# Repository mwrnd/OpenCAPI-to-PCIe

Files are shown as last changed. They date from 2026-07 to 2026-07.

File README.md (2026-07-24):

# PCIe to OpenCAPI-Compatible SlimSAS 8x

The [Open Coherant Accelerator Processor Interface (OpenCAPI)](https://opencapi.org/wp-content/uploads/2022/07/OpenCAPI-Overview.pdf) [was a standard](https://opencapi.org/2022/08/09/cxl-consortium-and-opencapi-consortium-sign-letter-of-intent-to-transfer-opencapi-specifications-to-cxl/) that had FPGA-based [Advanced Accelerated Cable (AAC)](https://files.openpower.foundation/s/xSQPe6ypoakKQdq/download/25Gbps-spec-20171108.pdf) [Add-In cards](https://opencapi.org/wp-content/uploads/2018/12/OpenCAPI-Tech-SC18-Exhibitor-Forum.pdf) such as [ADM-PCIE-9H3](https://www.alpha-data.com/product/adm-pcie-9h3/), [ADM-PCIE-9H7](https://www.alpha-data.com/alpha-data-release-adm-pcie-9h7-data-center-board-with-xilinx-virtex-ultrascale-hbm-fpga/), [ADM-PCIE-9V3](https://www.alpha-data.com/product/adm-pcie-9v3/), [ADM-PCIE-9V5](https://www.alpha-data.com/product/adm-pcie-9v5/), [BittWare XUP-VV4](https://www.bittware.com/fpga/xup-vv4/), [BittWare XUP-VVH](https://www.bittware.com/fpga/xup-vvh/), and [Nvidia Innova-2 Flex](https://www.nvidia.com/en-us/networking/ethernet/innova-2-flex/).

The OpenCAPI SlimSAS interface is based on [PCI-Express](https://en.wikipedia.org/wiki/PCI_Express). This project is an adapter capable of connecting such FPGA boards to host systmes with PCIe.

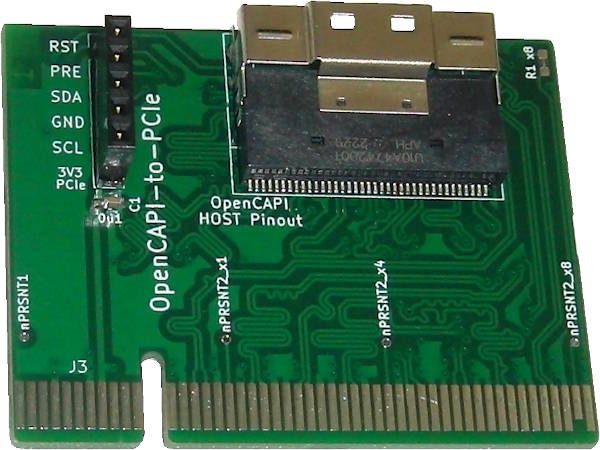
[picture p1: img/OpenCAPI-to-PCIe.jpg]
OpenCAPI-to-PCIe Adapter


This design uses the OpenCAPI pinout from the [ADM-PCIE-9V5 User Manual (Pg15-19of38)](https://www.alpha-data.com/xml/user_manuals/adm-pcie-9v5%20user%20manual_v1_4.pdf):

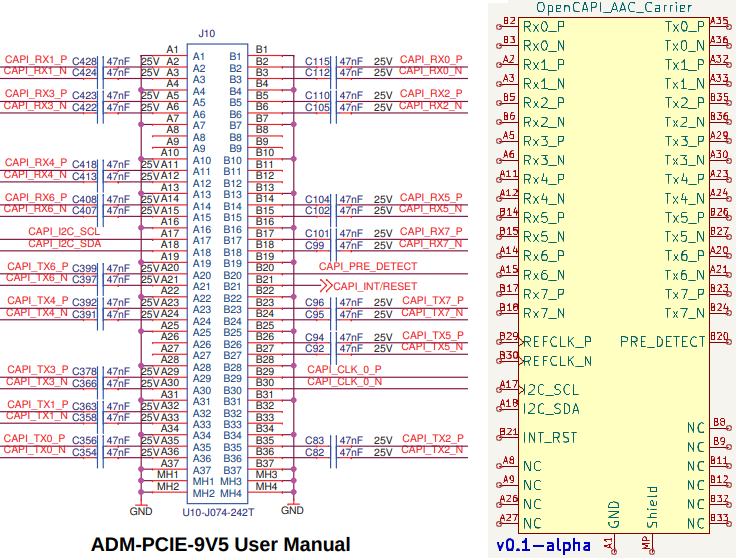
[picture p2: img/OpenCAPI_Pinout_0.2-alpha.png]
OpenCAPI Pinout from


The only OpenCAPI board I have to test against is the **Innova-2 MNV303212A-ADLT Rev:A2** and I designed the [OpenCAPI-to-PCIe_for_MNV303212A_RevA2](https://github.com/mwrnd/OpenCAPI-to-PCIe_for_MNV303212A_RevA2) project as an optimized variant of this design for that board.

## Issues when used with the Innova-2 MNV303212A RevA2

The [current v0.2 release](https://github.com/mwrnd/OpenCAPI-to-PCIe/releases/tag/v0.2) of this project worked with the [First Release of the `innova2_xdma_opencapi`](https://github.com/mwrnd/innova2_xdma_opencapi/tree/348716249bafc39514cb1a422a8e2fb5f301f859) project:

```
git clone --revision=348716249bafc39514cb1a422a8e2fb5f301f859 https://github.com/mwrnd/innova2_xdma_opencapi.git
wget https://github.com/mwrnd/innova2_xdma_opencapi/releases/download/v0.1/innova2_xdma_opencapi_bitstream.zip
```

But, it required a [non-standard GTY Channel to PCIe Lane mapping](https://github.com/mwrnd/innova2_xdma_opencapi/blob/348716249bafc39514cb1a422a8e2fb5f301f859/compile.tcl#L14) that Vivado complains about:

Vivado Critical Warning about Lane Ordering

The [OpenCAPI-to-PCIe_for_MNV303212A_RevA2](https://github.com/mwrnd/OpenCAPI-to-PCIe_for_MNV303212A_RevA2) project is a version of this adapter optimized for the Innova-2 **MNV303212A Rev:A2**.

# PCB Layout

4-Layer PCB. Inner 2 layers are GND planes. Differential pairs are matched to a length of 65mm +/- 1mm both inter-pair and intra-pair (N-to-P).

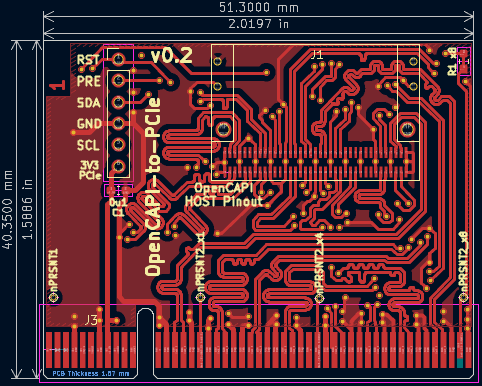
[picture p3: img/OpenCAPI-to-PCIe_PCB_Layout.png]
OpenCAPI to PCIe x8 PCB Layout


# Schematic

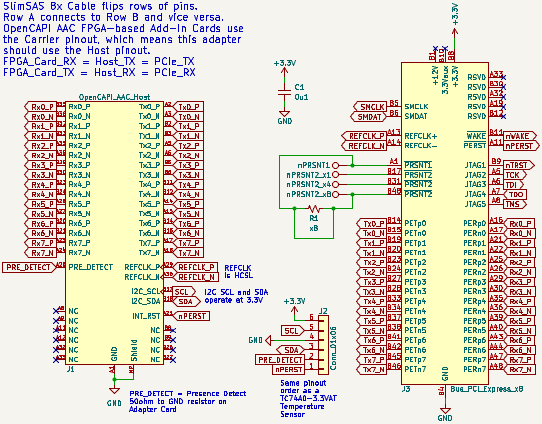
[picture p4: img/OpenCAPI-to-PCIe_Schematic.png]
OpenCAPI to PCIe x8 Schematic


## Design Notes

Refer to the [ADM-PCIE-9V5 User Manual (Pg15-19of38)](https://www.alpha-data.com/xml/user_manuals/adm-pcie-9v5%20user%20manual_v1_4.pdf). Useful [High Speed Design presentation](https://www.youtube.com/watch?v=QG0Apol-oj0&t=2832s).

Only a single component is needed for the adapter, a [U10A474200T](https://www.digikey.com/en/products/detail/amphenol-cs-commercial-products/U10A474200T/14632855)/[U10A474240T](https://www.digikey.com/en/products/detail/amphenol-cs-commercial-products/U10A474240T/17066204) SlimSAS 8x Right-Angle SMD Connector.

A SlimSAS 8x Cable such as the [3M 8ES8-1DF21](https://www.trustedparts.com/en/search/8ES8-1DF21)([Datasheet](https://multimedia.3m.com/mws/media/1398233O/3m-slimline-twin-ax-assembly-sff-8654-x8-30awg-78-5100-2665-8.pdf)) is required to use the adapter with an OpenCAPI FPGA Board.

Resistor **R1** is shorted to connect `nPRSNT1` to `nPRSNT2_x8`. The trace can be scratched off and `nPRSNT1` can be connected to `nPRSNT2_x1` or `nPRSNT2_x4` to limit the PCIe lane width.

Additional useful signals from the OpenCAPI connector are routed to a 6x1 0.1" Header ([DigiKey](https://www.digikey.com/en/products/detail/sullins-connector-solutions/PPTC061LFBN-RC/810145)). The pinout matches a [TC74 I2C Temperature Sensor](https://www.microchip.com/en-us/product/tc74) ([DigiKey](https://www.digikey.com/en/products/detail/microchip-technology/TC74A0-3-3VAT/442720)) for testing I2C. I2C pull-ups are on the AAC Add-in card. Note 3.3V is from the PCIe connector. **PRE** is a Presence Detect pin which is connected to GND via a 50-Ohm resistor on the OpenCAPI AAC Add-In card. **RST** is connected to PCIe/OpenCAPI RESET.

### PCB Stackup

I am using values from [JLCPCB](https://jlcpcb.com/capabilities/pcb-capabilities).

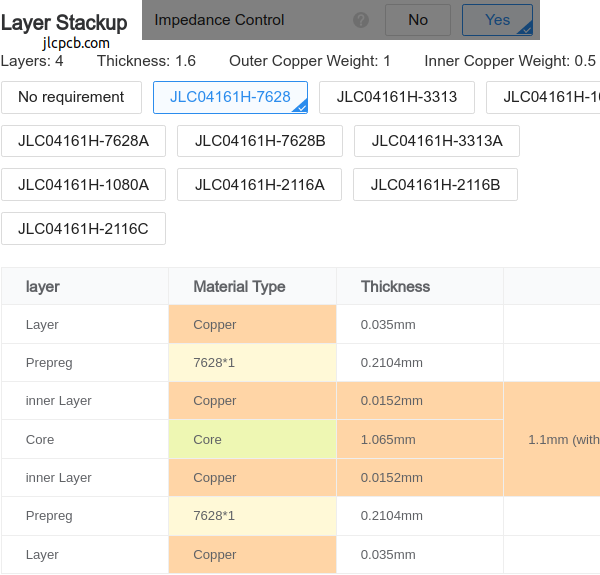
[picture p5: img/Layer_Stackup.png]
4-Layer Stackup


### Trace Impedance Control

OpenCAPI uses 85ohm impedance cables. I played with the values until I got the loosest differential pair coupling that is manufacturable with larger tolerances.

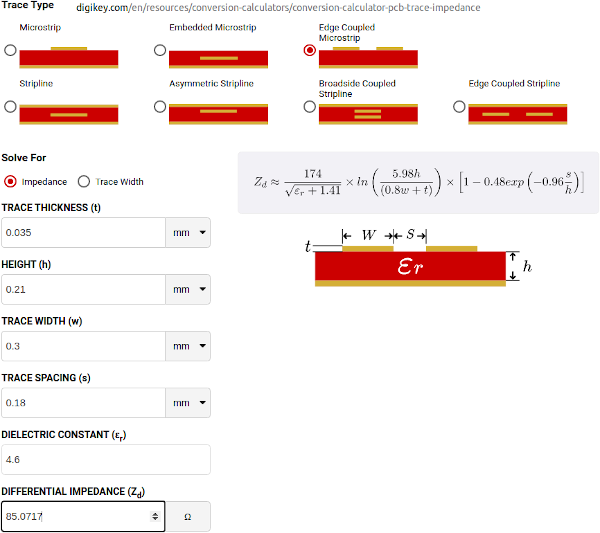
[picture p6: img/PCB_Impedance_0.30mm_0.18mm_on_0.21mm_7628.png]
85ohm Differential Impedance in DigiKey Calculator


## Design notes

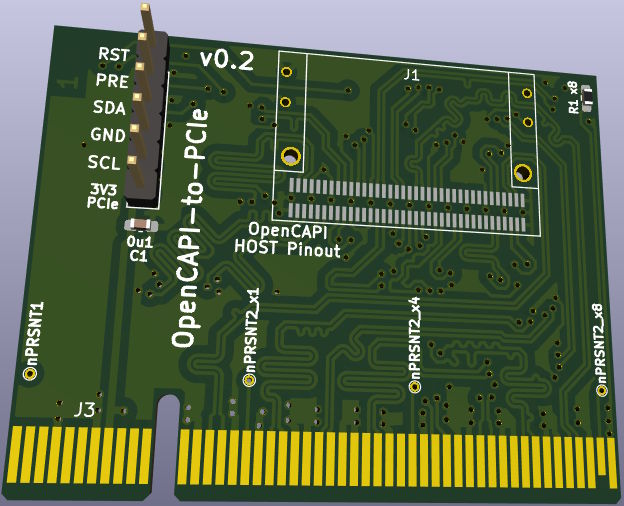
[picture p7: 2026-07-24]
img/OpenCAPI-to-PCIe_3D.jpg

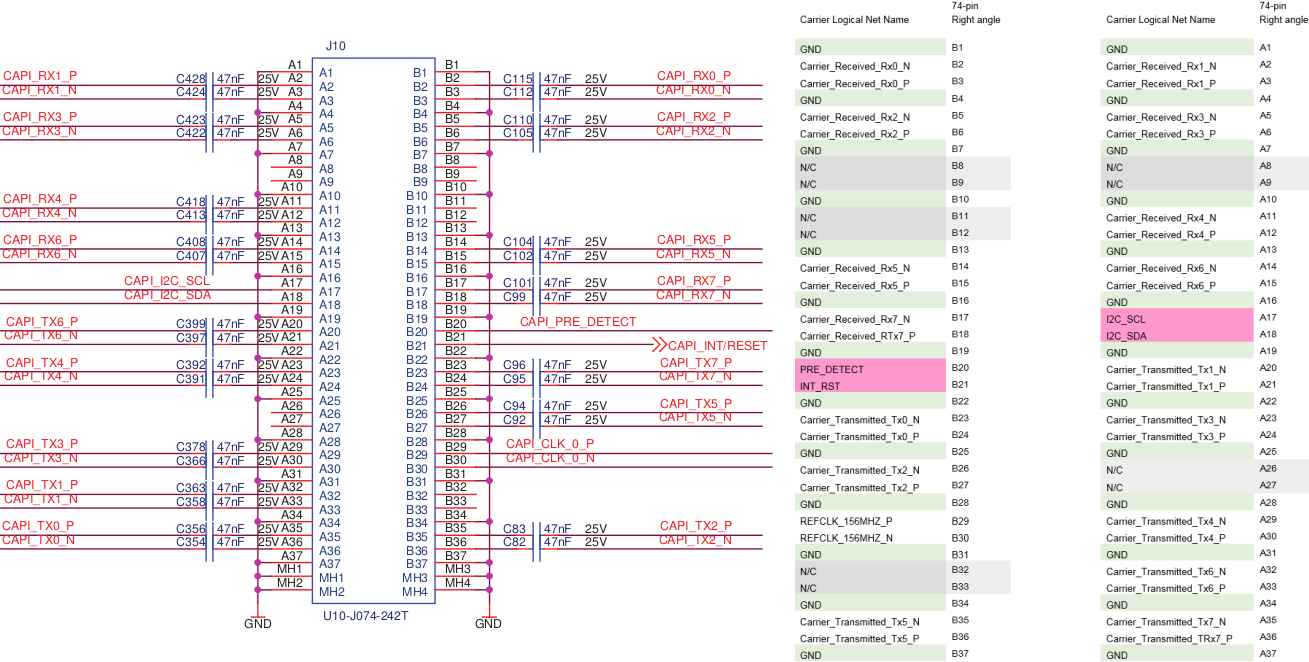
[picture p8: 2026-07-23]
img/OpenCAPI_Error.png

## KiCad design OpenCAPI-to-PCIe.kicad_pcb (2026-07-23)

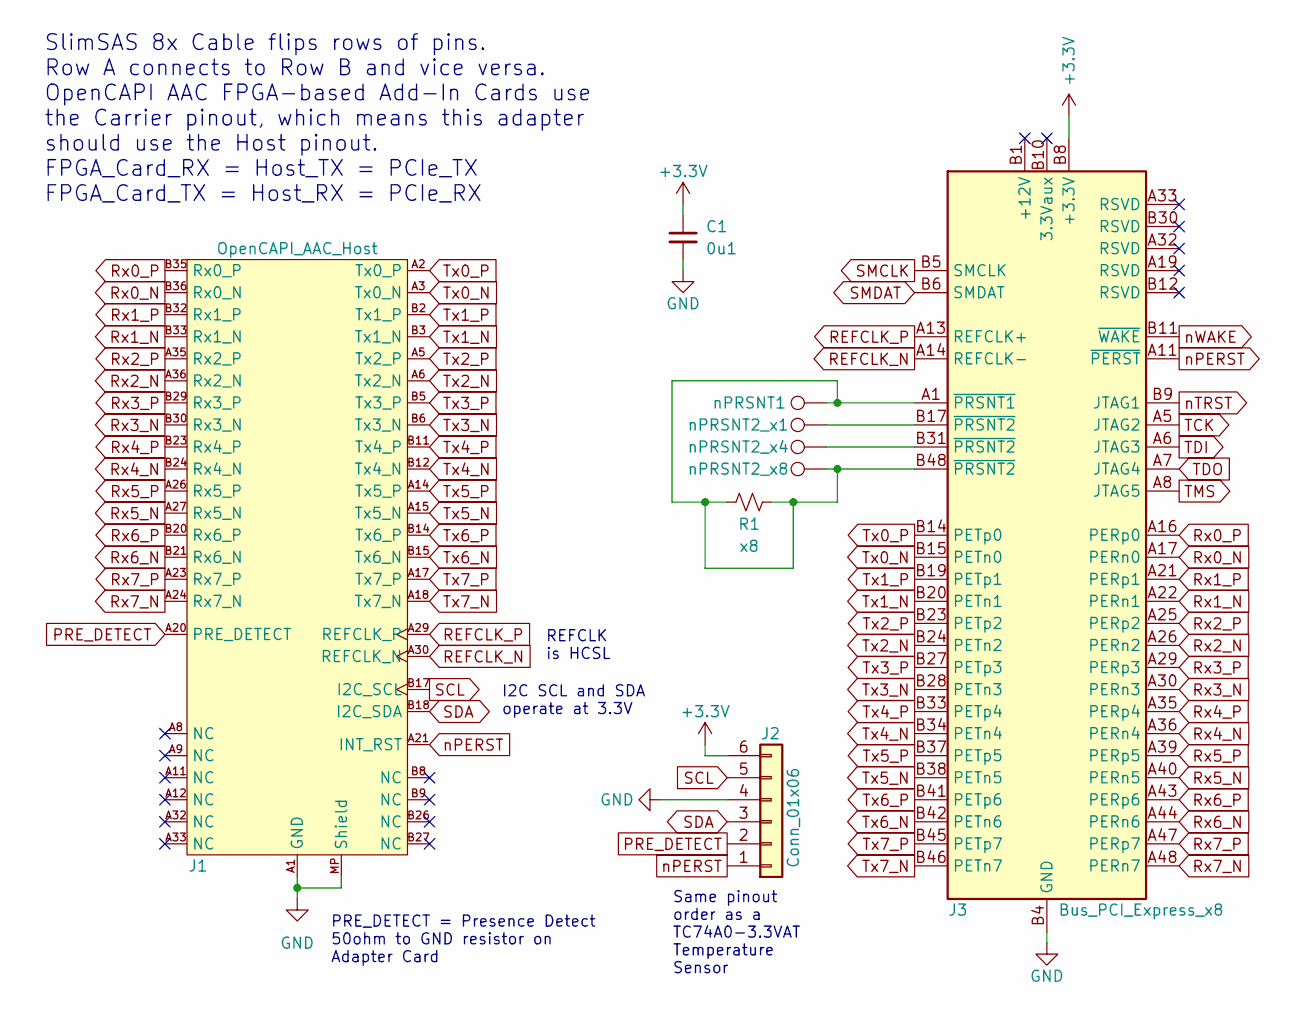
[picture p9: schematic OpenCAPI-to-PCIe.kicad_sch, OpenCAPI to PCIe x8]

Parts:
C1: 0u1; C_0603_1608Metric_Pad1.08x0.95mm_HandSolder
J1: OpenCAPI_AAC_Host; SlimSAS_8x_RA_U10-A474
J2: Conn_01x06; PinHeader_1x06_P2.54mm_Vertical
J3: Bus_PCI_Express_x8; BUS_PCIexpress_x8
R1: x8; R_0603_1608Metric_Pad0.98x0.95mm_HandSolder
TP1: nPRSNT1; TestPoint_THTPad_D1.0mm_Drill0.5mm
TP2: nPRSNT2_x1; TestPoint_THTPad_D1.0mm_Drill0.5mm
TP3: nPRSNT2_x4; TestPoint_THTPad_D1.0mm_Drill0.5mm
TP5: nPRSNT2_x8; TestPoint_THTPad_D1.0mm_Drill0.5mm

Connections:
+3.3V: C1.1, J2.6, J3.A9 (+3.3V), J3.A10 (+3.3V), J3.B8 (+3.3V)
GND: C1.2, J1.A1 (GND), J1.A4 (GND), J1.A7 (GND), J1.A10 (GND), J1.A13 (GND), J1.A16 (GND), J1.A19 (GND), J1.A22 (GND), J1.A25 (GND), J1.A28 (GND), J1.A31 (GND), J1.A34 (GND), J1.A37 (GND), J1.B1 (GND), J1.B4 (GND), J1.B7 (GND), J1.B10 (GND), J1.B13 (GND), J1.B16 (GND), J1.B19 (GND), J1.B22 (GND), J1.B25 (GND), J1.B28 (GND), J1.B31 (GND), J1.B34 (GND), J1.B37 (GND), J1.MP (Shield), J2.4, J3.A4 (GND), J3.A12 (GND), J3.A15 (GND), J3.A18 (GND), J3.A20 (GND), J3.A23 (GND), J3.A24 (GND), J3.A27 (GND), J3.A28 (GND), J3.A31 (GND), J3.A34 (GND), J3.A37 (GND), J3.A38 (GND), J3.A41 (GND), J3.A42 (GND), J3.A45 (GND), J3.A46 (GND), J3.A49 (GND), J3.B4 (GND), J3.B7 (GND), J3.B13 (GND), J3.B16 (GND), J3.B18 (GND), J3.B21 (GND), J3.B22 (GND), J3.B25 (GND), J3.B26 (GND), J3.B29 (GND), J3.B32 (GND), J3.B35 (GND), J3.B36 (GND), J3.B39 (GND), J3.B40 (GND), J3.B43 (GND), J3.B44 (GND), J3.B47 (GND), J3.B49 (GND)
unnamed: J3.A1 (~PRSNT1), J3.B48 (~PRSNT2), R1.1, R1.2, TP1.1, TP5.1
unnamed: J3.B17 (~PRSNT2), TP2.1
unnamed: J3.B31 (~PRSNT2), TP3.1
PRE_DETECT: J1.A20 (PRE_DETECT), J2.2
REFCLK_N: J1.A30 (REFCLK_N), J3.A14 (REFCLK-)
REFCLK_P: J1.A29 (REFCLK_P), J3.A13 (REFCLK+)
Rx0_N: J1.B36 (Rx0_N), J3.A17 (PERn0)
Rx0_P: J1.B35 (Rx0_P), J3.A16 (PERp0)
Rx1_N: J1.B33 (Rx1_N), J3.A22 (PERn1)
Rx1_P: J1.B32 (Rx1_P), J3.A21 (PERp1)
Rx2_N: J1.A36 (Rx2_N), J3.A26 (PERn2)
Rx2_P: J1.A35 (Rx2_P), J3.A25 (PERp2)
Rx3_N: J1.B30 (Rx3_N), J3.A30 (PERn3)
Rx3_P: J1.B29 (Rx3_P), J3.A29 (PERp3)
Rx4_N: J1.B24 (Rx4_N), J3.A36 (PERn4)
Rx4_P: J1.B23 (Rx4_P), J3.A35 (PERp4)
Rx5_N: J1.A27 (Rx5_N), J3.A40 (PERn5)
Rx5_P: J1.A26 (Rx5_P), J3.A39 (PERp5)
Rx6_N: J1.B21 (Rx6_N), J3.A44 (PERn6)
Rx6_P: J1.B20 (Rx6_P), J3.A43 (PERp6)
Rx7_N: J1.A24 (Rx7_N), J3.A48 (PERn7)
Rx7_P: J1.A23 (Rx7_P), J3.A47 (PERp7)
SCL: J1.B17 (I2C_SCL), J2.5
SDA: J1.B18 (I2C_SDA), J2.3
SMCLK: J3.B5 (SMCLK)
SMDAT: J3.B6 (SMDAT)
TCK: J3.A5 (JTAG2)
TDI: J3.A6 (JTAG3)
TDO: J3.A7 (JTAG4)
TMS: J3.A8 (JTAG5)
Tx0_N: J1.A3 (Tx0_N), J3.B15 (PETn0)
Tx0_P: J1.A2 (Tx0_P), J3.B14 (PETp0)
Tx1_N: J1.B3 (Tx1_N), J3.B20 (PETn1)
Tx1_P: J1.B2 (Tx1_P), J3.B19 (PETp1)
Tx2_N: J1.A6 (Tx2_N), J3.B24 (PETn2)
Tx2_P: J1.A5 (Tx2_P), J3.B23 (PETp2)
Tx3_N: J1.B6 (Tx3_N), J3.B28 (PETn3)
Tx3_P: J1.B5 (Tx3_P), J3.B27 (PETp3)
Tx4_N: J1.B12 (Tx4_N), J3.B34 (PETn4)
Tx4_P: J1.B11 (Tx4_P), J3.B33 (PETp4)
Tx5_N: J1.A15 (Tx5_N), J3.B38 (PETn5)
Tx5_P: J1.A14 (Tx5_P), J3.B37 (PETp5)
Tx6_N: J1.B15 (Tx6_N), J3.B42 (PETn6)
Tx6_P: J1.B14 (Tx6_P), J3.B41 (PETp6)
Tx7_N: J1.A18 (Tx7_N), J3.B46 (PETn7)
Tx7_P: J1.A17 (Tx7_P), J3.B45 (PETp7)
nPERST: J1.A21 (INT_RST), J2.1, J3.A11 (~PERST)
nTRST: J3.B9 (JTAG1)
nWAKE: J3.B11 (~WAKE)

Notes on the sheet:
I2C SCL and SDA operate at 3.3V
Same pinout order as a TC74A0-3.3VAT Temperature Sensor
REFCLK is HCSL
SlimSAS 8x Cable flips rows of pins. Row A connects to Row B and vice versa. OpenCAPI AAC FPGA-based Add-In Cards use the Carrier pinout, which means this adapter should use the Host pinout. FPGA_Card_RX = Host_TX = PCIe_TX FPGA_Card_TX = Host_RX = PCIe_RX
PRE_DETECT = Presence Detect 50ohm to GND resistor on Adapter Card

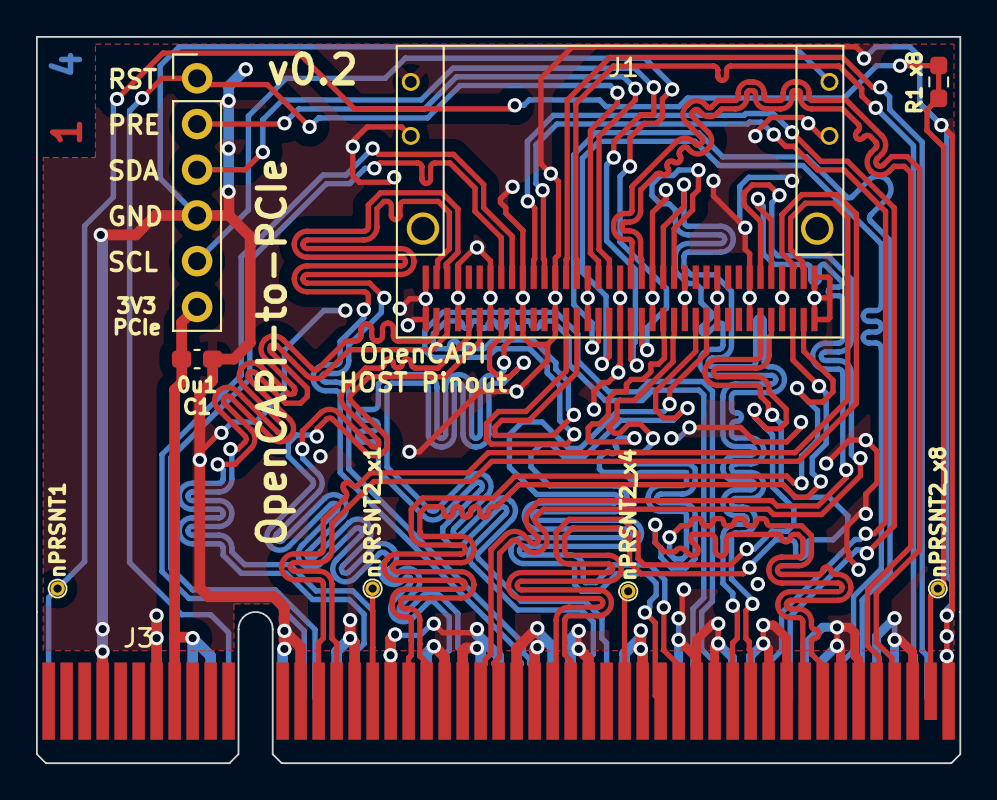
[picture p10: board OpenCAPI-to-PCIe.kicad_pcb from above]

Board: 4 copper layers, 51.3 x 40.4 mm, 9 parts (0 on the bottom side), 43 nets.
